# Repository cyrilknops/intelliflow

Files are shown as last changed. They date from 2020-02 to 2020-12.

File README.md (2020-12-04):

# Intelliflow
Intelliflow is a IoT project made by Cyril Knops, Joost Van der Linden, Ferre Claes, Glen Van Puyenbroeck and Emile Knaepen. The goal is to design a pcb and firmware for the [ESP32](https://www.espressif.com/en/products/socs/esp32/overview) that can interface with generic sensors and communicate with a dashboard. The data that is send to the dashboard are the different sensor values.
## System Overview
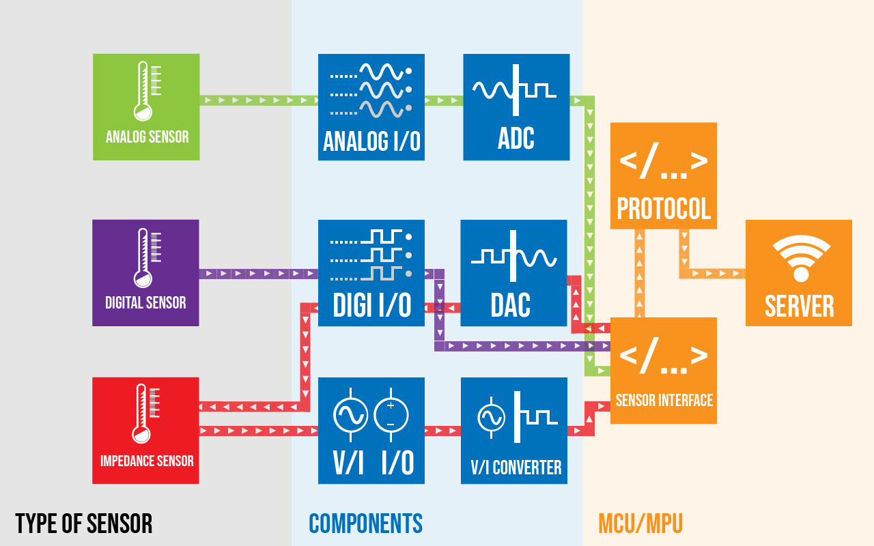
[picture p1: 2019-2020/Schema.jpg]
Flowdiagram

## How to use
There are a few differen directories with each its own project:
* [dashboard written in angularjs](https://github.com/cyrilknops/intelliflow/tree/master/test-dashboard)
* [firmware for sending temperatures to the server](https://github.com/cyrilknops/intelliflow/tree/master/MQTT%2BProtobuf/Intelliflow)
* [firmware to change the settings of the esp](https://github.com/cyrilknops/intelliflow/tree/master/Console)
* [a test firmware that tests the speed of the different protocols (MQTT, Wi-Fi and protobuf)](https://github.com/cyrilknops/intelliflow/tree/master/IntelliflowAN)

most of them have a readme file in them which explains how to use and configure the different tings
## Build with
* [C](https://en.wikipedia.org/wiki/C_(programming_language)) - The programming language used
* [MQTT](http://mqtt.org/) - The communication protocol used
* [Sparkfun ESP32 Thing](https://www.sparkfun.com/products/13907) - The development boeard used
## Authors
* Cyril Knops - ESP32 Network, ESP32 CLI
* Joost Van der Linden - ESP32 Sensor connection
* Glen Van Puyenbroeck - PCB Design
* Ferre Claes - Sensor components
* Emile Knaepen - ESP32 Sensor Libraries
* Bart Stukken - Scrum master
* Koen Gilissen - Product owner
## Links
[Component list](https://hogeschoolpxl-my.sharepoint.com/:x:/r/personal/11800025_student_pxl_be/_layouts/15/Doc.aspx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)
<br/>
[Order list](https://hogeschoolpxl-my.sharepoint.com/:x:/g/personal/11700872_student_pxl_be/ETT0oJHQHUZLjarLOVaMEmgBshADOvq9l2GqsdMUGDBhIA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)
<br/>
[Wiki](https://github.com/cyrilknops/intelliflow/wiki)

## License
This project is licensed under the MIT License

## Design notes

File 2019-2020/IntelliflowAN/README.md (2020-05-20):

# Speed test for the ESP32
This project can test for 3 things:
* Wi-Fi connection
* Protobuf conversion
* MQTT connection

## Configuration
In the config.h file change the following things
```c
const char* ssid = "Your_ssid";
const char* password = "Your_pwd";
const char* mqtt_server = "intelliflow.pxl-ea-ict.be"; //change this to your mqtt broker adress
```
## How to run
Open the project in arduino ide and upload to the ESP32

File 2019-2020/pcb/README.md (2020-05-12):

# PCB Prototype 

Here you can find the schematics of the PCB prototype. 

Included in this workspace: 

- 3D map : In this map are the used 3D models of the prototype
- PCB_Project : Here in this map are the schematics , project and PCB files of the project

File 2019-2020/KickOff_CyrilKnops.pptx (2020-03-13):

## Intelliflow

Cyril Knops

## Probleemstelling

- In de voedings industrie is het vaak onduidelijk wat er in het proces gebreurd.
  - Er worden weinig tot geen sensoren gebruikt
  - Hierdoor worden tonnen/liters gronstoffen soms weggegooid
  - Waardevolle tijd verspild omdat complete processen moeten worden onderbroken

## Materiaal & methoden

- Een simple MPU met externe ADC+DAC
  - Goedkoper wanneer er geen ADC nodig is
  - Hogere resolutie bij externe ADC+DAC
  - Meer keuze qua MPU vb: esp(ingebouwde WIFI)
  - Stroom naar spanning converter
- Welke methoden ga ik gebruiken
  - Low overhead netwerk protocol
  - Meerdere sensoren per MPU mogelijk
  - High throughput protocol tussen ADC/DAC en MPU

## Milestones

- 17/03/20 24u
  - Definitieve keuze MPU ADC/DAC Network Protocol
- 31/03/20 24u
  - 1st demo-implementatie 1 sensor op breadboard
  - (PCB frezen)
- 28/04/20 24u
  - Implementatie sofware meerdere sensoren compleet
- 19/05/20 24u
  - Definitief project
  - (PCB af)
- 27/05/20 8u30
  - Extra controle

## Taakverdeling

- Cyril
  - Hoofdverantwoordelijke voor algemene integratie
  - Verantwoordelijke voor Communicatie met server
- Rein
  - Verantwoordelijke voor sensor interface
- Glen
  - Verantwoordelijke voor PCB design
- Ferre
  - Verantwoordelijke voor component keuze/inlezen ADC/DAC

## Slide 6

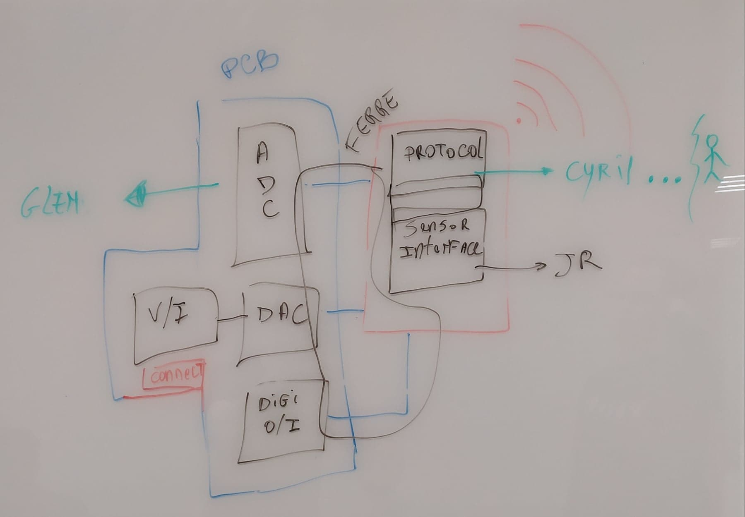
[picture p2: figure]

## Onderzoeksvraag

- Hoe kunnen we op een economische en ecologische manier verschillende stoffen meten en omzetten naar bruikbare data om het voedsel process te stroomlijnen?

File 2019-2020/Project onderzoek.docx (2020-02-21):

Project onderzoek.

Notities Microcontroller ESP32 mogelijkheden .

Datum : 21/02/2020

Input spanning : 2.3 – 3.6 volt.

Gebruikt arduino IDE voor de software.

Onderdelen :

- Processoren:
  - CPU: Xtensa dual-core (of single-core) 32-bit LX6 microprocessor, klokfrequentie van 160 of 240 MHz. (Achterhoofd houden)
  - Ultra-low power (ULP) co-processor Leuk extra
- Geheugen: 520 KiB SRAM (https://nl.wikipedia.org/wiki/Static_random-access_memory)
- Draadloze verbindingsmogelijkheden:
  - Wi-Fi: 802.11 (https://nl.wikipedia.org/wiki/IEEE_802.11) b/g/n
  - Bluetooth: v4.2 BR / EDR en BLE
- Perifere interfaces:
  - 12-bit SAR ADC (https://nl.wikipedia.org/wiki/Analoog-digitaalomzetter) tot 18 kanalen (lage ADC , ligt wel iets hoger dan de ESP8226 (10 bit))

ADC voor intelloflow project zou 21 bit moeten zijn

Externe ADC mogelijk ? (zie pagina 2)

  - 2 × 8-bit DAC's (https://nl.wikipedia.org/wiki/Digitaal-analoogomzetter) (Heel laag )
  - 10 × aanraaksensoren (GPIO's met capacitieve detectie)
  - 4 × SPI (https://nl.wikipedia.org/wiki/Serial_Peripheral_Interface)
  - 2 × I²S- interfaces
  - 2 × I²C (https://nl.wikipedia.org/wiki/I%C2%B2C-bus) interfacebus
  - 3 × UART
  - SD (https://nl.wikipedia.org/wiki/SD-kaart) / SDIO (https://nl.wikipedia.org/wiki/SD-kaart) / CE-ATA / MMC (https://nl.wikipedia.org/wiki/MMC-kaart) / eMMC (https://nl.wikipedia.org/wiki/MMC-kaart) hostcontroller
  - SDIO / SPI-slave-controller
  - Ethernet (https://nl.wikipedia.org/wiki/Ethernet) MAC-interface met speciale ondersteuning voor DMA en IEEE 1588 Precision Time Protocol
  - CAN bus (https://nl.wikipedia.org/wiki/Controller_Area_Network) 2.0
  - Infrarood afstandsbediening (TX / RX, maximaal 8 kanalen)
  - Motor PWM (https://nl.wikipedia.org/wiki/Pulsbreedtemodulatie)
  - LED PWM (https://nl.wikipedia.org/wiki/Pulsbreedtemodulatie) (tot 16 kanalen)
  - Hall-effect sensor (https://nl.wikipedia.org/wiki/Hall-sensor)
- Beveiligingstechnieken:
  - Standaard IEEE 802.11-beveiligingsfuncties die worden ondersteund, inclusief WFA, WPA / WPA2 en WAPI
  - Beveiligd opstartproces
  - Flash-codering
  - 1024-bit OTP, tot 768-bit voor klanten
  - Cryptografische hardwareversnelling: AES (https://nl.wikipedia.org/wiki/Advanced_Encryption_Standard), SHA-2, RSA (https://nl.wikipedia.org/wiki/RSA_(cryptografie)), elliptische curve-cryptografie (ECC), random number generator (RNG)
- Stroombeheer:
  - Interne drop-out regelaar (https://nl.wikipedia.org/wiki/Spanningsregelaar)
  - 5μA stroom in deep-sleep mode Leuk extra
  - Wake up van sleep mode door GPIO interrupt, timer, ADC of interrupt door capacitieve aanraaksensor. (Totaal interruptslijnen = 32 )

Bron Algemene informatie = https://nl.wikipedia.org/wiki/ESP32

Bron interrupts = https://lastminuteengineers.com/handling-esp32-gpio-interrupts-tutorial/

Externe ADC’s zijn mogelijk tot 24 bit. Component ads1256 gaat tot 24 bit

.http://www.ti.com/lit/ds/symlink/ads1256.pdf

Bibliotheek hoeft niet zelf geschreven te worden. Is vrij beschikbaar.

https://www.youtube.com/watch?v=LjLwvXKz2x8

Conclusie :

- Makkelijk programmeerbaar.
- Code ivm met wifi is duidelijk en makkelijk toe te passen.
- Open source code is makkelijk te vinden.
- Heeft veel eigen bibliotheken .
- Mogelijkheid voor de ADC drastisch te verhogen met de ads1256 component
- Bibliotheek voor de ADS1256 moet niet zelf geschreven worden , vrij beschikbaar.
- Samples per seconde kan makkelijk aangepast worden

Verdere onderzoek voor een andere dag:

- Verschillende bordjes beschikbaar van de ADS1256. Welke is betrouwbaar ?
- Technische specificaties van de ADS1256 is bekijken.
- Code is bestuderen.
- Prijzen opzoeken.
- Ook mogelijkheid met ESP8266 , PSOC6 wifi en andere ?

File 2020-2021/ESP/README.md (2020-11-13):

# instructions

Add a config.h to the root of your arduino project containing the following:
``` c++
const char* ssid = "SSID"; //change this to the SSID of your Wi-Fi network
const char* password = "*********"; //change this to the password of your Wi-Fi network
const char* mqtt_server = "home.iwg-it.com"; // change this to your mqtt broker url or ip
const int mqtt_port = 24075; //change this to your mqtt broker port
```

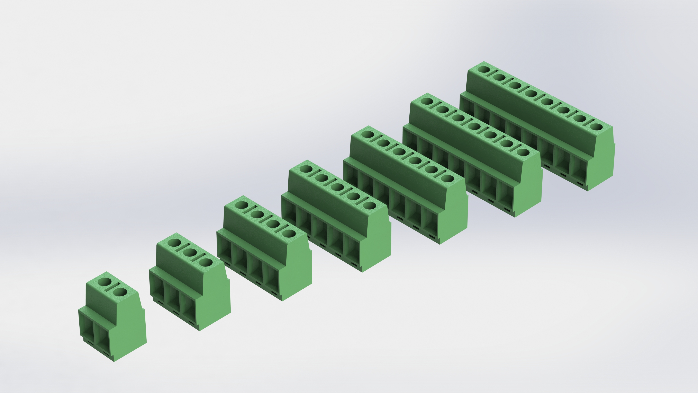
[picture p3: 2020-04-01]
2020-2021/PCB/PCBontwerpen/3D/em2929-series-euromag-terminal-blocks-1.snapshot.2/Rendering.JPG

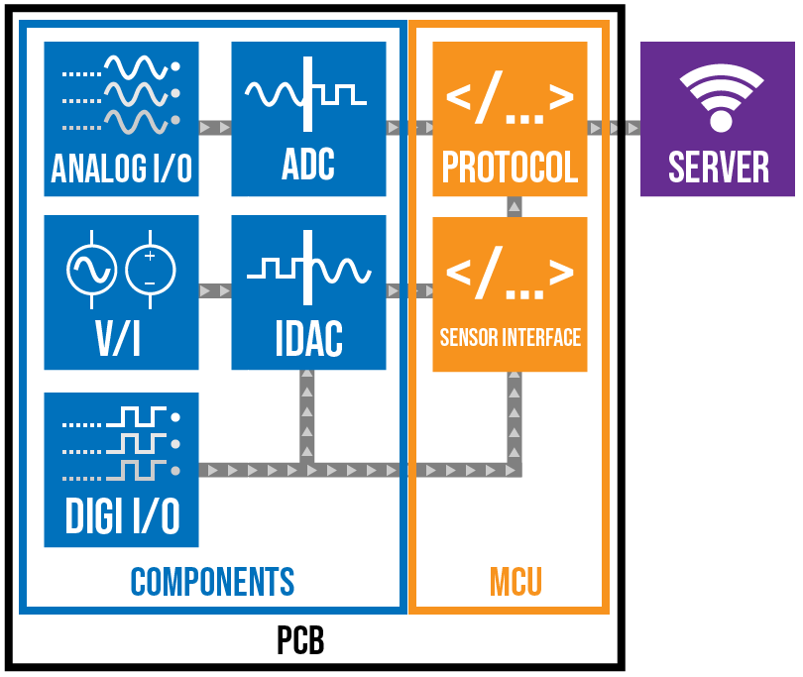
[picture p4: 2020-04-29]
2019-2020/2020-04-26 14_32_01-Untitled-1.ai_ @ 100% (RGB_Preview).png

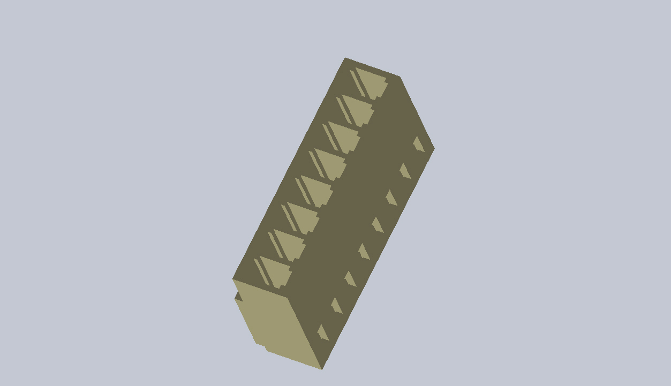
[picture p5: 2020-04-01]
2020-2021/PCB/PCBontwerpen/3D/CI32 8 PIN FEMALE_3.JPG

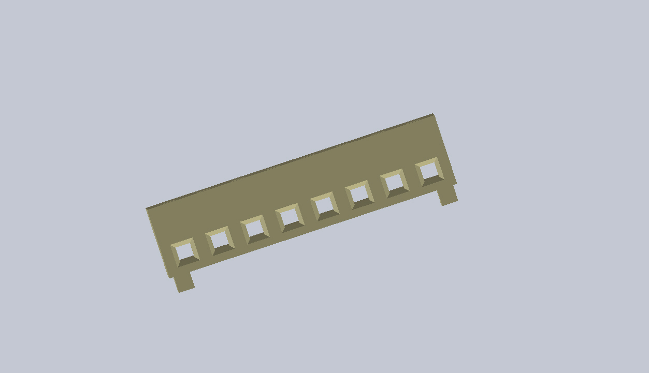
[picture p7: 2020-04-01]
2020-2021/PCB/PCBontwerpen/3D/CI32 8 PIN FEMALE_2.JPG

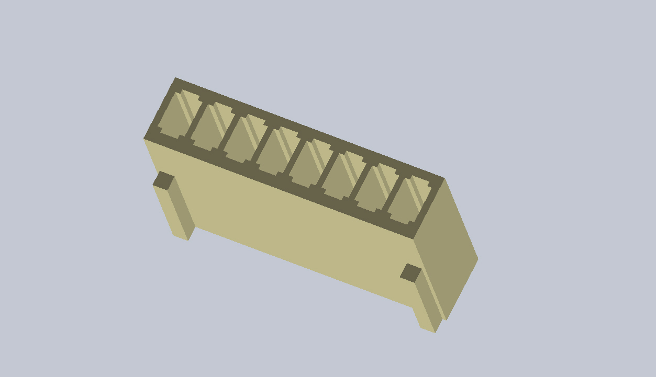
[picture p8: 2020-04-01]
2020-2021/PCB/PCBontwerpen/3D/CI32 8 PIN FEMALE_.JPG

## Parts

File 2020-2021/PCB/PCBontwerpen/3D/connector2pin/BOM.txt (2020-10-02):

3DX_CUI_DEVICES_Supplier: CUI Devices
3DX_CUI_DEVICES_Description: 2~24 Poles, Screwless, 45°, 5.00 Pitch, 26~14 (AWG), Terminal Block Connector
3DX_CUI_DEVICES_Model Number: TBL007A-500-02GY

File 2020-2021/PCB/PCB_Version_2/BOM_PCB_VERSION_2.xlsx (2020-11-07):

Beschrijving | Regular ID | Link | ID Mouser | Price/Piece | Amount/PCB | Total/PCB | Form
ESP32 | NodeMCU-32 | https://www.az-delivery.de/en/products/esp32-developmentboard?_pos=13&_sid=d3f4f9e85&_ss=r | NodeMCU-32 | EUR 7.99 | 1 | EUR 7.99 | Trough Hole
Terminal Block Size 2 | TB004-508-02BE | https://www.mouser.be/ProductDetail/CUI-Devices/TB004-508-02BE | 490-TB004-508-02BE | EUR 0.53 | 2 | EUR 1.06 | Trough Hole
Terminal Block Size 4 | TB004-508-04BE | https://www.mouser.be/ProductDetail/CUI-Devices/TB004-508-04BE | 490-TB004-508-04BE | EUR 0.81 | 6 | EUR 4.86 | Trough Hole
Terminal Block Size 8 | TB004-508-08BE | https://www.mouser.be/ProductDetail/CUI-Devices/TB004-508-08BE | 490-TB004-508-08BE | EUR 1.30 | 1 | EUR 1.30 | Trough Hole
ADC | ADS1247IPWR | https://www.mouser.be/ProductDetail/Texas-Instruments/ADS1247IPWR?qs=XGzIaZb%2FFYLO0W6RE5uyhw%3D%3D | 595-ADS1247IPWR | EUR 8.07 | 1 | EUR 8.07 | IC
DAC | DAC70504RTET | https://www.mouser.be/ProductDetail/Texas-Instruments/DAC70504RTET | 595-DAC70504RTET | EUR 11.69 | 1 | EUR 11.69 | IC
OP-AMP | LTC6241CS8#PBF | https://www.mouser.be/ProductDetail/?qs=hVkxg5c3xu%252BfRCzMDOZ5vQ%3D%3D | 584-LTC6241CS8#PBF | EUR 2.64 | 1 | EUR 2.64 | IC
DIP-Switch | CES-0402MC | https://www.mouser.be/ProductDetail/Nidec-Copal/CES-0402MC?qs=XeJtXLiO41Q05topIs8SoQ%3D%3D | 229-CES-0402MC | EUR 1.37 | 1 | EUR 1.37 | Trough Hole
Header Set | PRT-14311 | https://www.mouser.be/ProductDetail/SparkFun/PRT-14311?qs=YCa%2FAAYMW01YBV4voM9QGw%3D%3D | 474-PRT-14311 | EUR 1.37 | 1 | EUR 1.37 | Trough Hole
DC-Power socket | PJ-002BH | https://www.mouser.be/ProductDetail/CUI-Devices/PJ-002BH?qs=WyjlAZoYn51nOX1h%2FqpLlg%3D%3D | 490-PJ-002BH | EUR 0.63 | 1 | EUR 0.63 | Trough Hole
Capaciteit (1µF) | C0805X105K8RAC7210 | https://www.mouser.be/ProductDetail/KEMET/C0805X105K8RAC7210 | 80-C0805X105K8RACLR | EUR 0.75 | 1 | EUR 0.75 | SMD 0805
Capaciteit (0,1µF) | C0805X104M5RACTU | https://www.mouser.be/ProductDetail/KEMET/C0805X104M5RACTU | 80-C0805X104M5RACTU | EUR 0.44 | 2 | EUR 0.88 | SMD 0805
Capaciteit (1nF) | C0805X102F5GACTU | https://www.mouser.be/ProductDetail/KEMET/C0805X102F5GACTU?qs=AQlKX63v8RtxfgGJTbOcaw%3D%3D | 80-C0805X102F5G | EUR 1.59 | 1 | EUR 1.59 | SMD 0805
Weerstand (47Ω) | ERA-6VEB47R0V | https://www.mouser.be/ProductDetail/Panasonic/ERA-6VEB47R0V | 667-ERA-6VEB47R0V | EUR 0.59 | 5 | EUR 2.95 | SMD 0805
Weerstand (500Ω) | RN732ATTD5000B25 | https://www.mouser.be/ProductDetail/KOA-Speer/RN732ATTD5000B25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 | 660-RN732ATTD5000B25 | EUR 0.71 | 2 | EUR 1.43 | SMD 0805
 |  |  |  |  | Total Price: | EUR 48.58

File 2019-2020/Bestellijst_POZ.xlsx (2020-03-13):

Mouser |  |  |  | Reichelt |  |  |  | Conrad |  |  |  | Extra
Link | ID | Price | Amount | Link | ID | Price | Amount | Link | ID | Price | Amount | Link | ID | Price | Amount
 |  | EUR 0.00 | 0 |  |  | EUR 0.00 | 0 |  |  | EUR 0.00 | 0 |  |  | EUR 0.00 | 0
TOTAL |  | EUR 0.00 | 0 |  |  | EUR 0.00 | 0 |  |  | EUR 0.00 | 0 |  |  | EUR 0.00 | 0

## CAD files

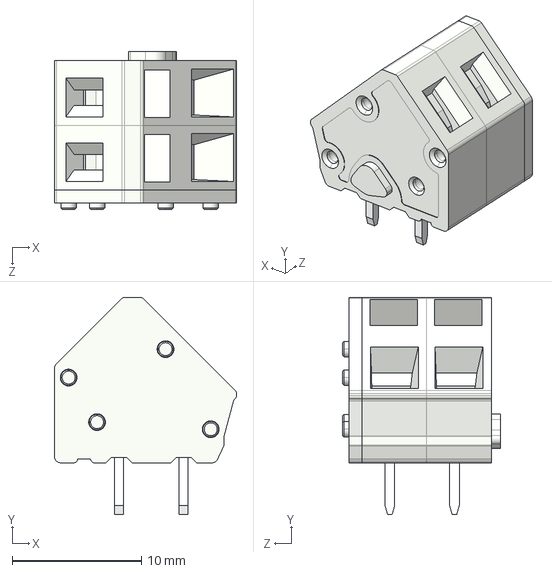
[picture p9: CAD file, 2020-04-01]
2019-2020/pcb/PCBontwerpen/3D/connector2pin/CUI_DEVICES_TBL007A-500-02GY.step
14.1 x 16.8 x 12.2 mm

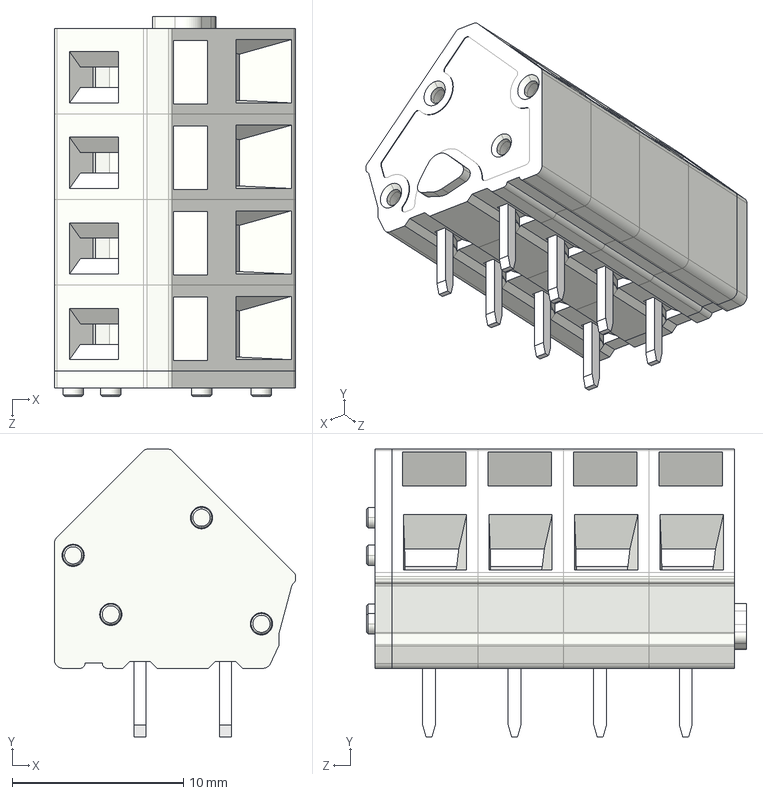
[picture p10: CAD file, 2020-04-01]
2019-2020/pcb/PCBontwerpen/3D/connector4pin/CUI_DEVICES_TBL007A-500-04GY.step
14.1 x 16.8 x 22.2 mm

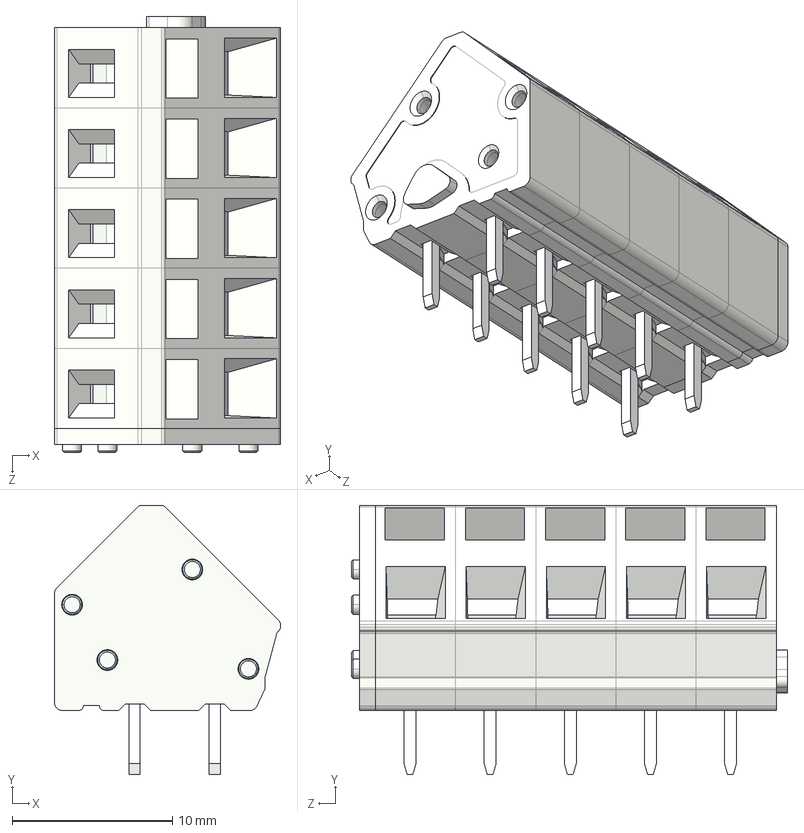
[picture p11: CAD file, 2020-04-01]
2019-2020/pcb/PCBontwerpen/3D/connector5pin/CUI_DEVICES_TBL007A-500-05GY.step
14.1 x 16.8 x 27.2 mm

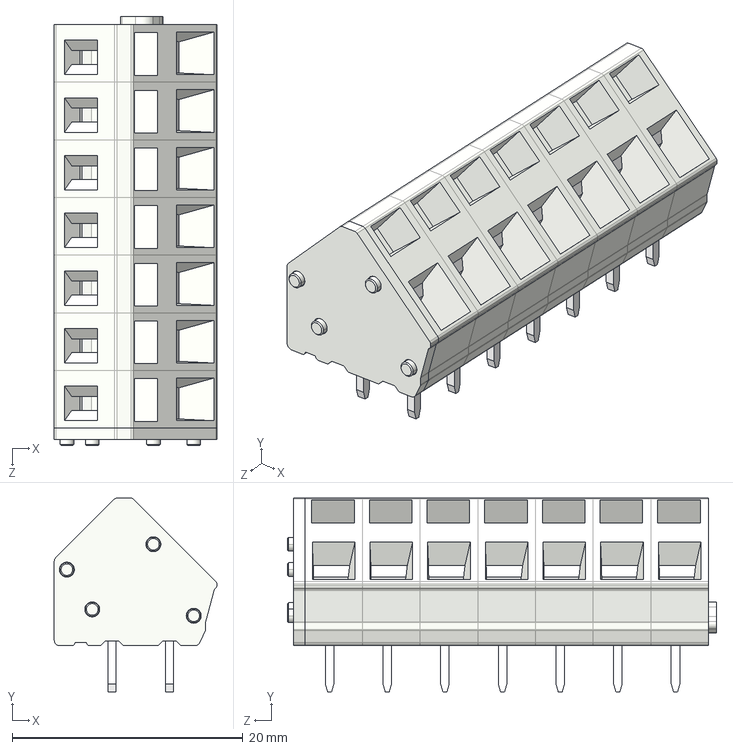
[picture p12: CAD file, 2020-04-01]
2019-2020/pcb/PCBontwerpen/3D/connector7pin/CUI_DEVICES_TBL007A-500-07GY.step
14.1 x 16.8 x 37.2 mm

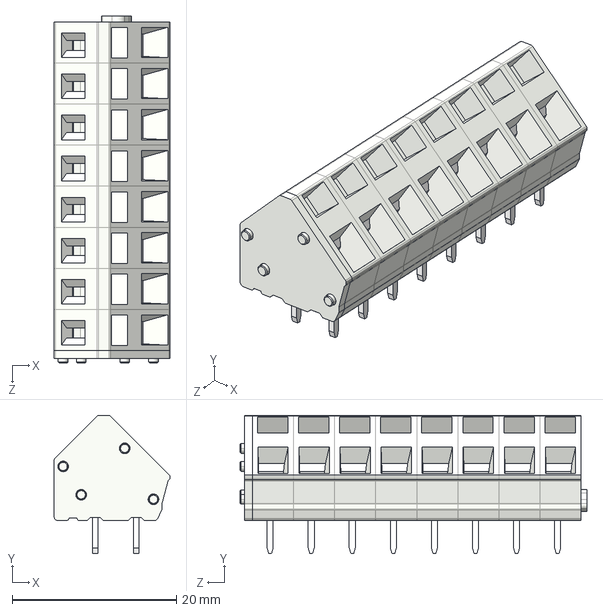
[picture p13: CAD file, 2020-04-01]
2019-2020/pcb/PCBontwerpen/3D/connector8/CUI_DEVICES_TBL007A-500-08GY.step
14.1 x 16.8 x 42.2 mm

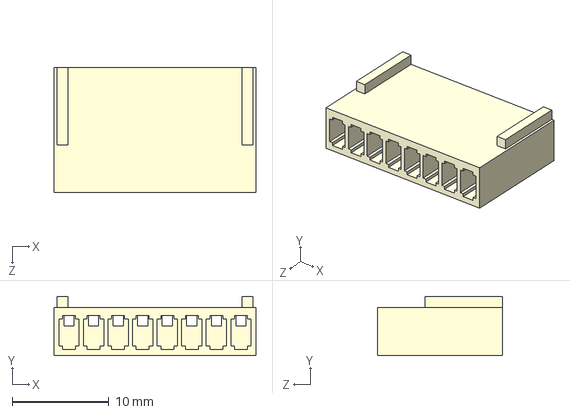
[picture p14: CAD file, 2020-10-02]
2020-2021/PCB/PCBontwerpen/3D/CI32 8 PIN FEMALE_.STEP
20.9 x 6.15 x 13.0 mm

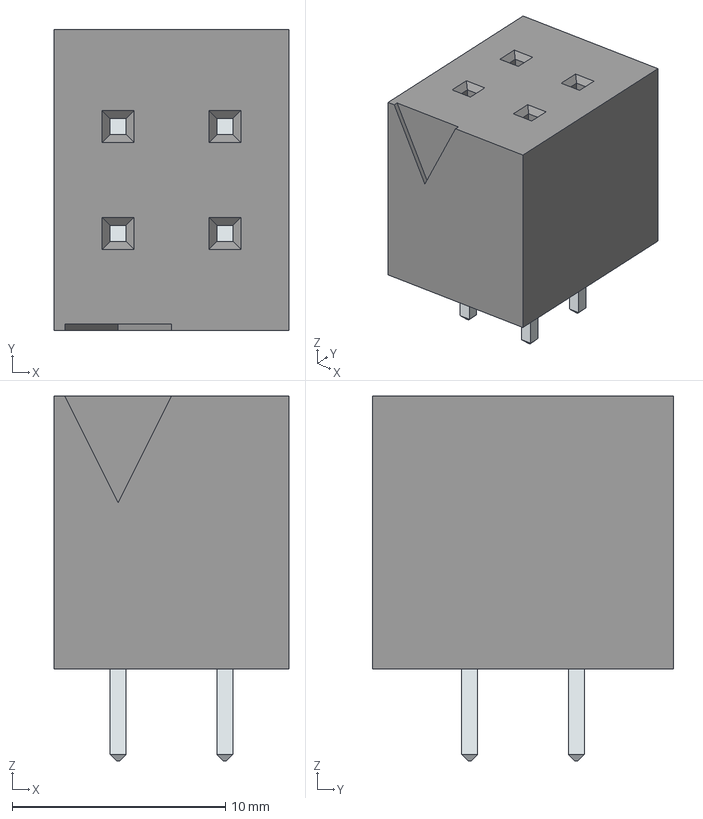
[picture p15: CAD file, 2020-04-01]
2020-2021/PCB/PCBontwerpen/3D/TBL007A-500-02GY/3D/TBL007A-500-02GY.stp
11.0 x 14.1 x 17.1 mm
LeadsArray

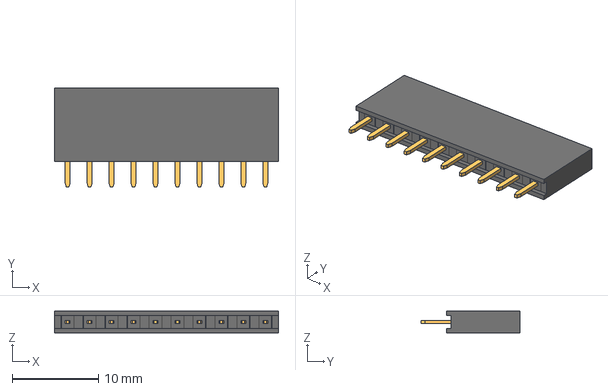
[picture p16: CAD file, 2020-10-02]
2020-2021/PCB/PCBontwerpen/3D/zl262-10s_p2-54_l25-9_w2-5_h8-5.stp
25.9 x 11.5 x 2.54 mm

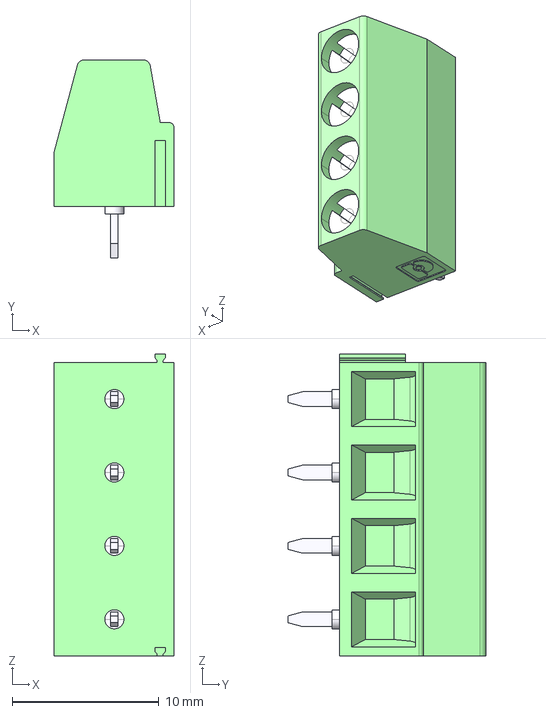
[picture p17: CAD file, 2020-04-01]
2019-2020/pcb/PCBontwerpen/3D/1729034/3D/1729034.stp
8.15 x 13.5 x 20.6 mm

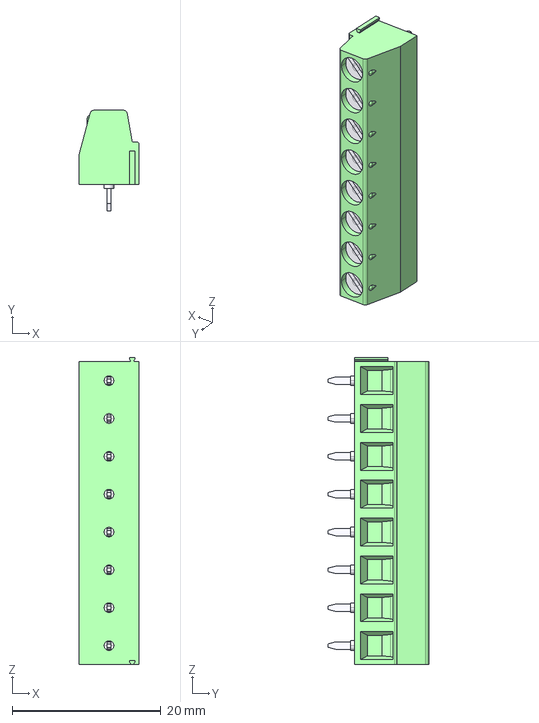
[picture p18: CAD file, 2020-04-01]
2019-2020/pcb/PCBontwerpen/3D/1729186/3D/1729186.stp
8.10 x 13.5 x 41.2 mm

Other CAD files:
2020-2021/PCB/PCBontwerpen/3D/connector2pin/CUI_DEVICES_TBL007A-500-02GY.step
2020-2021/PCB/PCBontwerpen/3D/connector4pin/CUI_DEVICES_TBL007A-500-04GY.step
2020-2021/PCB/PCBontwerpen/3D/connector5pin/CUI_DEVICES_TBL007A-500-05GY.step
2020-2021/PCB/PCBontwerpen/3D/connector7pin/CUI_DEVICES_TBL007A-500-07GY.step
2020-2021/PCB/PCBontwerpen/3D/connector8/CUI_DEVICES_TBL007A-500-08GY.step
2020-2021/PCB/PCBontwerpen/3D/1729034/3D/1729034.stp
2020-2021/PCB/PCBontwerpen/3D/1729186/3D/1729186.stp
2020-2021/PCB/PCBontwerpen/3D/CI32 8 PIN FEMALE_.IGS
2020-2021/PCB/PCBontwerpen/3D/CI32 8 PIN FEMALE_.SLDPRT
2020-2021/PCB/PCBontwerpen/3D/TBL007A-500-02GY.stl
2020-2021/PCB/PCBontwerpen/3D/TBL007A-500-02GY/3D/TBL007A-500-02GY.stl
2020-2021/PCB/PCBontwerpen/3D/em2929-series-euromag-terminal-blocks-1.snapshot.2/EM292902-UL.SLDPRT
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

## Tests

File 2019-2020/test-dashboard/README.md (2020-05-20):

# Test dashboard
This dashboard is created to test the MQTT and REST API connection to the server.

# Configuration
Change the URL in the index.html file to the URL where your server is running

# How to run
Just download the files and open the index.html

# Buid with
* [AngularJS framwork](https://angularjs.org/) - the framework that makes it all work

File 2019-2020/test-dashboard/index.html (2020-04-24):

# Intelliflow

Show list

Amount of measurements: {{vm.amount}} | | Current Temp: {{vm.temp}} | | Time of measurement: {{vm.timestamp | date : "dd/mm/yy 'at' HH:mm:ss"}}
Timestamp | temperature
{{temp.time | date : "dd/mm/yy 'at' HH:mm:ss"}} | {{temp.temperature}}

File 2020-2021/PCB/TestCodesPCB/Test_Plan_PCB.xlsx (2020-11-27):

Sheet: PCB v1
Testplan PCB
Short | Test | No heat | Heat
 | No Heat ADC | x
 | No Heat DAC | x
 | No Heat ESP32 | x
 | No Heat capacitors | x
Comment | Everything seems fine , ADC is a little warm but temp stays constant
Volt and ground | Test | Present | Not present
 | 3,3 V where 3,3V should be | x
 | 5 V where 5V should be | x
Comment | 3,29V = 3,3V
GPIO's ESP32 | Test Input | Succes | Failed
 | GPIO39 / ADC 3 |  |  | forgot to document , recheck
 | GPIO34 / ADC 6 | x
 | GPIO35 / ADC 7 | x
 | GPIO32 / ADC 4 | x
Comment | Test is done with a analog light sensor
GPIO's ESP32 | Test output | Succes | Failed
 | GPIO36 / ADC0 ( SS DAC) |  | x | input only
 | GPIO39 / ADC 3 |  | x | input only
 | GPIO34 / ADC 6 |  | x | input only
 | GPIO35 / ADC 7 |  | x | input only
 | GPIO32 / ADC 4 | x
 | GPIO5 (SS OUTBOARD) | x
 | GPIO15 (SS ADC) | x
 | GPIO2 (START ADC) | x
 | GPIO8 (DRYD ADC) |  | x | only 1,17 volt doenst turn of
 | GPIO7 (RESET ADC) |  | x
Comment | date = 24/10/2020 . Maybey only input pins (39,34,35,32) ? Recheck datasheet
 | date = 25/10/2020 . Pin 33 went high in a previous test but not pin 32 ? Recheck pin .
 | data = 25/10/2020. Pin 36 is wrongly placed , should be an output , test should fail
 | date = 30/10/2020, Test completed , pin GPIO7 and GPIO8 failed (check datasheet)
 | date = 30/10/2020, GPIO8 needs to go low after converting (see 9,4,4) | GPIO8 can be used as MOSI
 | date = 30/10/2020, GPIO7 doesnt go high (see 9.4.2) | GPIO7 can be used as MISO
UART | Test | Succes | Failed
 | An UART module works |  |  | optional
 | Sending and recieving string | x
Comment | test done with psoc 4
I2C | Test | Succes | Failed
 | Reading data I2C sensor | x
 | Sending and recieving string
Comment | Test is done with a tempature sensor (SCL and SDA are switched)
SPI | Test | Succes | Failed
 | Reading data SPI sensor |  |  | optional
 | Sending and recieving charaters | x
Comment | test done with psoc 4
ADC 1247 | Test | Succes | Failed
 | Connection possible with SPI |  |  | cancelled due to hardware problems
 | Reading an analog sensor |  |  | cancelled due to hardware problems
Comment
DAC 70504 | Test | Succes | Failed
 | Connection possible with SPI |  |  | cancelled due to hardware problems
 | Output current is |  |  | cancelled due to hardware problems
Comment

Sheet: Speedcheck PCB v1
UART | Recieving data on | Recieved | Not received
 | 1200 bps | x
 | 2400 bps | x
 | 4800 bps | x
 | 9600 bps | x
 | 19200 bps | x
 | 38400 bps | x
 | 57600 bps | x
 | 115200 bps | x
Comment | 08/11/2020 = Test completed with psoc4 no errors
 | note : esp32 can't be programmend with TX pluged in
 | https://learn.sparkfun.com/tutorials/serial-communication/all
I2C part 1 | Measerment SCL | Approved | Not approved
 | Standard mode : 100 Kbit/s |  |  | Not the possibility for measerment I2C bus on avaible oscilloscope
 | Fast mode : 400 Kbit/s |  |  | Not the possibility for measerment I2C bus on avaible oscilloscope
 | Recieved data on | Recieved | Not recieved
 | Standard mode : 100 Kbit/s | x
 | Fast mode : 400 Kbit/s | x
Comment | 10/11/2020 = MCP9808 temp sensor got 100 khz and 400 khz posibility , test completed
 | https://dcubestore.com/product/mcp9808-high-accuracy-digital-temperature-sensor-%C2%B10-25-from-40c-to-125c-i2c-mini-module/
SPI OUTBOARD | SPI half duplex on (sending data to psoc 4) | Approved | Failed
 | 24 MHZ |  | x | Somtimes corruption in data
 | 12 MHZ | x
 | 6 MHZ | x
 | 3 MHZ | x
 | 1,5 MHZ | x
Comment | 22/11/2020 = test completed. Note: bitwise << 1 is needed while sending to psoc , loss LSB bit
 | 27/11/2020 = Lost LSB fit is from the PSOC SPI block https://community.cypress.com/thread/26206?start=0&tstart=0
 | SPI full duplex on (sending and recieving data psoc 4) | Recieved data | Failed
 | 24 MHZ |  | x | More corruption in data
 | 12 MHZ | x
 | 6 MHZ |  | x | ESP MISO recieves garbage , psoc MOSI recieves data as normal
 | 3 MHZ |  | x | ESP MISO recieves garbage , psoc MOSI recieves data as normal
 | 1,5 MHZ |  | x | ESP MISO recieves garbage , psoc MOSI recieves data as normal
Comment | 22/11/2020 = test completed, only 12MHZ on MISO ?
 | 27/11/2020 = changing external clock doenst have effect on SPI block psoc https://community.cypress.com/thread/26206?start=0&tstart=0
SPI ADC 1247 | Measerment SCLK to ADC 1247 | Approved | Not approved
 | SPI_CLOCK_DIV2 = 80 MHZ |  |  | cancelled due to hardware problems
 | SPI_ClOCK_DIV8 = 20 MHZ |  |  | cancelled due to hardware problems
 | SPI_ClOCK_DIV32 = 5 MHZ |  |  | cancelled due to hardware problems
 | SPI_ClOCK_DIV128 = 1,25 MHZ |  |  | cancelled due to hardware problems
 | Recieved data on | Recieved | Not recieved
 | SPI_CLOCK_DIV2 = 80 MHZ |  |  | cancelled due to hardware problems
 | SPI_ClOCK_DIV8 = 20 MHZ |  |  | cancelled due to hardware problems
 | SPI_ClOCK_DIV32 = 5 MHZ |  |  | cancelled due to hardware problems
 | SPI_ClOCK_DIV128 = 1,25 MHZ |  |  | min is 480 ns or around 2 Mhz , should fail
Comment
SPI DAC 70504 | Measerment SCLK to DAC 70504 | Approved | Not approved
 | SPI_CLOCK_DIV2 = 80 MHZ |  |  | cancelled due to hardware problems
 | SPI_ClOCK_DIV8 = 20 MHZ |  |  | cancelled due to hardware problems
 | SPI_ClOCK_DIV32 = 5 MHZ |  |  | cancelled due to hardware problems
 | SPI_ClOCK_DIV128 = 1,25 MHZ |  |  | cancelled due to hardware problems
 | Recieved data on | Recieved | Not recieved
 | SPI_CLOCK_DIV2 = 80 MHZ |  |  | cancelled due to hardware problems
 | SPI_ClOCK_DIV8 = 20 MHZ |  |  | cancelled due to hardware problems
 | SPI_ClOCK_DIV32 = 5 MHZ |  |  | cancelled due to hardware problems
 | SPI_ClOCK_DIV128 = 1,25 MHZ |  |  | cancelled due to hardware problems
Comment

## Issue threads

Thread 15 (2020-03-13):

voorbereiding pcb ontwerp designen in Altuim.

Reinvanderlinden, 2020-03-13:
Connectoren en componenten toevoegen in altium

Glen-tech, 2020-03-18:
- ADC footprint en schematic is in orde gebracht
- Alle connectoren schematic en footprints zijn in orde ( 4 pins , 5 pins en 8 pins zelf moeten maken).

**DAC en ESP moet nog toegevoegt worden**

Glen-tech, 2020-03-20:
ESP schematic toegevoegt

ESP footprint , DAC + current to voltage moet nog worden toegevoegt

Glen-tech, 2020-03-31:
Alle footprints en 3d moddelen werden toegevoegt . Bewijs hiervan volgt nog.

Glen-tech, 2020-05-06:
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

Closed 2020-05-06.

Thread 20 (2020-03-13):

Connector Sensor-ADC/DAC

Reinvanderlinden, 2020-03-13:

Glen-tech, 2020-03-14:
- Connectoren zonder schroef werd uitgekozen
- Alle 3 dezelfde merk plus dezelfde kleur
- 3 leveranciers gevonden , laatste lijkt me niet 100 betrouwbaar

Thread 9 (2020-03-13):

Het opstellen van de elektrische schema voor breadboard prototype en test PCB's.

Reinvanderlinden, 2020-03-13:

Glen-tech, 2020-03-20:
- ADC circuit is toegevoegt , alleen condensatoren en SPI verbinding zou nog gedaan moeten worden.
- DAC circuit moet nog volledig gedaan worden.

Glen-tech, 2020-05-06:
Volledige test schema is afgerond
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

Closed 2020-05-06.

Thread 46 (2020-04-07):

problems pcb

FerreClaes, 2020-04-07:

FerreClaes, 2020-04-07:
- [ ] reset adc niet aangesloten

- [ ] drdy adc niet aangesloten

Glen-tech, 2020-04-08:
-Alle T splitsingen is nakijken tegen volgende keer en de 45 graden hoeken.
-Condensatoren 8 , 9 , 10 en 11 verder uit elkaar zetten voor 45 graden hoeken te maken

Glen-tech, 2020-04-10:
- Connectie diktes werd aangepast
- Connectoren onder mogen wat verder uit elkaar

Glen-tech, 2020-04-10:
- Traces zijn nu op de juiste dikte
- Condensatoren moet nog gebeuren

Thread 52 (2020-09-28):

DAC schema en footprint

Glen-tech, 2020-09-28:
- Aanmaak Dac + toevoeging schema is gebeurd.
- Footprint moet nog aangemaakt worden.

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

Glen-tech, 2020-09-28:
2d en 3d footprint zitten erbij

dit klopt met de designators

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

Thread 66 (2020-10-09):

PCB Versie 1 uittesten

FerreClaes, 2020-10-09:

Glen-tech, 2020-10-13:
Test 1 (voeding) korte samenvatting
  - Geen rookvorming
  - ESP32 heeft normale temperatuur
  - Alles is 3.3 V waar het moet zijn en 5V waar het moet zijn
  - Geen warmte bij de DAC
  - Beetje warmte bij de ADC , dit blijft constant.

Glen-tech, 2020-10-15:
Test2 I2C en digitale ingangen

- I2C vertoont geen problemen  met uitlezen van sensoren (SDA en SCL tekst PCB staat omgedraait)
- Dit geld ook bij de connector digitale ingangen .

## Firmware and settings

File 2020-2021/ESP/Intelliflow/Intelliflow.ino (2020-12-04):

#include <EEPROM.h>
#include <WiFi.h>
#include <PubSubClient.h>
//protobuf includes
#include <pb.h>
#include <pb_common.h>
#include <pb_encode.h>
#include "intelliflow.pb.h"
//sensor includes
#include <Wire.h>
#include "Adafruit_TCS34725.h"
#include "Adafruit_SGP30.h"
//CLI  
#define LINE_BUF_SIZE 128   //Maximum input string length
#define ARG_BUF_SIZE 64     //Maximum argument string length
#define MAX_NUM_ARGS 8      //Maximum number of arguments
bool error_flag = false;
char line[LINE_BUF_SIZE];
char args[MAX_NUM_ARGS][ARG_BUF_SIZE];
int cmd_help();
int cmd_wifi();
int cmd_mqtt();
int (*commands_func[])(){
    &cmd_help,
    &cmd_wifi,
    &cmd_mqtt,
    &cmd_cli,
    
};
const char *commands_str[] = {
    "help",
    "wifi",
    "mqtt",
    "cli"
};
int num_commands = sizeof(commands_str) / sizeof(char *);
bool cliMode;
//Sensors
Adafruit_TCS34725 tcs = Adafruit_TCS34725(TCS34725_INTEGRATIONTIME_700MS, TCS34725_GAIN_1X);
Adafruit_SGP30 sgp;
//Settings
String ssid;
String password;
String url;
String port;
//wifi connection
WiFiClient espClient;
//mqtt
int trys = 0;
int wifiTrys = 0;
PubSubClient client(espClient);
long lastMsg = 0;
char msg[50];
uint32_t  messages = 0;
uint32_t succes = 0;
//protobuf
int values = 0;

void setup() {
  //status led
  pinMode(BUILTIN_LED, OUTPUT);
  //serialg
  Serial.begin(115200);
  EEPROM.begin(400);
  ssid = EEPROM.readString(0);
  password = EEPROM.readString(100);
  url = EEPROM.readString(200);
  port = EEPROM.readString(300);
  Serial.println("Settings:");
  Serial.print(ssid);
  Serial.print("|");
  Serial.println(password);
  Serial.println("-----------------------");
  Serial.print(url);
  Serial.print("|");
  Serial.println(port);
  Serial.println("-----------------------");
  Serial.println("Type cli to change these settings");
  cli_init();
  
  sgp.begin();
  tcs.begin();

  //wifi
  setup_wifi();
  //mqtt
  client.setServer(url.c_str(), port.toInt());
  client.setCallback(callback);
}

void loop() {
  if(!cliMode){
    if (!client.connected()) {
      if(trys < 2){
        reconnect();
      }
      else{
        Serial.println("failed:");
        Serial.println("There is a problem with mqtt, change the settings");
        cliMode = true;
        cmd_mqtt();
      }
    }else{    
      RGB_Sensor();
      Gas_Sensor();
      Temp_Sensor();
      delay(1000);
    } 
  }
    my_cli();
}

bool encode(intelliflow_Sensor &sensor){
  uint8_t buffer[50];
  pb_ostream_t stream = pb_ostream_from_buffer(buffer, sizeof(buffer));
  if(!pb_encode(&stream, intelliflow_Sensor_fields , &sensor)){
      Serial.println("Failed to encode");
  }else{
    for(int i = 0; i<stream.bytes_written; i++){
      Serial.printf("%02X",buffer[i]);
    }
    Serial.println("");
    if (!client.publish("sensor", buffer, stream.bytes_written)) {
        Serial.println(F("Publishing Failed"));
    } else {
        succes++;
        Serial.println(F("Publish succesful"));
    }
  }
}

void setup_wifi() {

  delay(10);
  // We start by connecting to a WiFi network
  Serial.println();
  Serial.print("Connecting to ");
  Serial.println(ssid);

  WiFi.begin(ssid.c_str(), password.c_str());

  while (WiFi.status() != WL_CONNECTED && !cliMode) {
    delay(500);
    Serial.print(".");
    wifiTrys++;
    if(wifiTrys >= 10){
      cliMode = true;
      Serial.println("");
      Serial.println("Could not connect, change wifi settings");
      cmd_wifi();
    }
  }

  randomSeed(micros());
  if(WiFi.status() == WL_CONNECTED){
    Serial.println("");
    Serial.println("WiFi connected");
    Serial.println("IP address: ");
    Serial.println(WiFi.localIP());
  }
}

void callback(char* topic, byte* payload, unsigned int length) {
  Serial.print("Message arrived [");
  Serial.print(topic);
  Serial.print("] ");
  for (int i = 0; i < length; i++) {
    Serial.print((char)payload[i]);
  }
  Serial.println();

  // Switch on the LED if an 1 was received as first character
  if ((char)payload[0] == '1') {
    digitalWrite(BUILTIN_LED, LOW);   // Turn the LED on (Note that LOW is the voltage level
    // but actually the LED is on; this is because
    // it is active low on the ESP-01)
  } else {
    digitalWrite(BUILTIN_LED, HIGH);  // Turn the LED off by making the voltage HIGH
  }

}

void reconnect() {
  // Loop until we're reconnected
  
  while (!client.connected() && trys <= 1) {
    Serial.print("Attempting MQTT connection...");
    // Create a random client ID
    String clientId = "ESP8266Client-";
    clientId += String(random(0xffff), HEX);
    // Attempt to connect
    if (client.connect(clientId.c_str())) {
      Serial.println("connected");
    } else {      
        Serial.print("failed, rc=");
        Serial.print(client.state());
        Serial.println(" try again in 5 seconds");
        delay(5000);
        trys++;
    }
  }
}

void RGB_Sensor(){ 
  uint16_t r, g, b, c, colorTemp, lux;
  tcs.getRawData(&r, &g, &b, &c);
  colorTemp = tcs.calculateColorTemperature(r, g, b);
  lux = tcs.calculateLux(r, g, b);
  
  intelliflow_Sensor sensor = intelliflow_Sensor_init_zero;
  strcpy(sensor.id, "1");
  sensor.value=colorTemp;
  strcpy(sensor.unit, "K");   
  Serial.println(sensor.value);
  Serial.println(sensor.id);
  Serial.println(sensor.unit);
  encode(sensor);
  Serial.println("-------------------------");
}

void Gas_Sensor(){
  if (! sgp.IAQmeasure()) {
    Serial.println("Measurement failed");
    return;
  }
  
  intelliflow_Sensor sensor = intelliflow_Sensor_init_zero;
  strcpy(sensor.id, "1");
  sensor.value=sgp.eCO2;
  strcpy(sensor.unit, "ppm");   
  Serial.println(sensor.value);
  Serial.println(sensor.id);
  Serial.println(sensor.unit);
  encode(sensor);
  Serial.println("-------------------------");
}

void Temp_Sensor(){
  int reading = analogRead(25);
  float Temp   = (reading - 509)/6.45;
  
  intelliflow_Sensor sensor = intelliflow_Sensor_init_zero;
  strcpy(sensor.id, "1");
  sensor.value=round(Temp);
  strcpy(sensor.unit, "°C");   
  Serial.println(sensor.value);
  Serial.println(sensor.id);
  Serial.println(sensor.unit);
  encode(sensor);
  Serial.println("-------------------------");
}

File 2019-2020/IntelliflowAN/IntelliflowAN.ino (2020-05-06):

#include "entry.pb.h"
#include <dht11.h>
#include "pb_common.h"
#include "pb.h"
#include "pb_encode.h"

#include <WiFi.h>
#include <PubSubClient.h>
#include "config.h"

#define DHT11PIN 4

//wifi connection
WiFiClient espClient;

//mqtt
PubSubClient client(espClient);
long lastMsg = 0;
char msg[50];
uint32_t  messages = 0;
uint32_t succes = 0;

//protobuf
uint8_t buffer[10];
int values = 0;

//temp sensor
dht11 DHT11;
Loggings_Log message = Loggings_Log_init_zero ;
pb_ostream_t stream = pb_ostream_from_buffer(buffer, sizeof(buffer));

//tests
bool wifisetup = false;
int testmode = 1;
uint32_t beforeTest = 0;
uint32_t afterTest  = 0;
uint32_t testDuration = 0;
void setup() {
  //serial
  Serial.begin(115200);
  //mqtt
  client.setServer(mqtt_server, 24075);
  client.setCallback(callback);
  
}

void loop() {
  switch(testmode){
    case 1: //test the wifi speed
      beforeTest = millis();
      setup_wifi();
      afterTest = millis();
      testDuration = afterTest - beforeTest;
      Serial.print("the wifi test took ");
      Serial.print(testDuration);
      Serial.println(" milliseconds");
      testmode = 2;
      break;
    case 2: //test the mqtt speed
      if(!wifisetup)
        setup_wifi();
      message.temperature = 55;
      if(!encode())
        Serial.println("encoding failed");
      if (!client.connected()) {
        reconnect();
      }
      beforeTest = millis();
      pub();
      afterTest = millis();
      testDuration = afterTest - beforeTest;
      Serial.print("the mqtt test took ");
      Serial.print(testDuration);
      Serial.println(" milliseconds");
      testmode = 3;
      break;
    case 3: //test the protobuf speed
      beforeTest = millis();
      message.temperature = 66;
      for(int i=0; i < 100; i++){
        encode();
        resetValues();
      }
      afterTest = millis();
      testDuration = afterTest - beforeTest;
      Serial.print("the protobuff test took ");
      Serial.print(testDuration);
      Serial.println(" milliseconds");
      testmode = 4;
      break;
  }
}

bool encode(){
  if(!pb_encode(&stream, Loggings_Log_fields, &message)){
      Serial.println("Failed to encode");
      return false;
  }
  return true;
}
bool pub(){
  messages++;
  if (!client.publish("temperature", buffer, stream.bytes_written)) {
    Serial.println(F("Publishing Failed"));
    resetValues();
  } else {
    succes++;
    Serial.println(F("Publish succesful"));
    resetValues();
  }
  Serial.print("succes-rate: ");
  Serial.print(succes);
  Serial.print("/");
  Serial.println(messages);
}

void setup_wifi() {
  wifisetup = true;
  delay(10);
  // We start by connecting to a WiFi network
  Serial.println();
  Serial.print("Connecting to ");
  Serial.println(ssid);

  WiFi.begin(ssid, password);

  while (WiFi.status() != WL_CONNECTED) {
    delay(500);
    Serial.print(".");
  }

  randomSeed(micros());

  Serial.println("");
  Serial.println("WiFi connected");
  Serial.println("IP address: ");
  Serial.println(WiFi.localIP());
}

void callback(char* topic, byte* payload, unsigned int length) {
  Serial.print("Message arrived [");
  Serial.print(topic);
  Serial.print("] ");
  for (int i = 0; i < length; i++) {
    Serial.print((char)payload[i]);
  }
  Serial.println();

  // Switch on the LED if an 1 was received as first character
  if ((char)payload[0] == '1') {
    digitalWrite(BUILTIN_LED, LOW);   // Turn the LED on (Note that LOW is the voltage level
    // but actually the LED is on; this is because
    // it is active low on the ESP-01)
  } else {
    digitalWrite(BUILTIN_LED, HIGH);  // Turn the LED off by making the voltage HIGH
  }

}

void reconnect() {
  // Loop until we're reconnected
  while (!client.connected()) {
    Serial.print("Attempting MQTT connection...");
    // Create a random client ID
    String clientId = "ESP8266Client-";
    clientId += String(random(0xffff), HEX);
    // Attempt to connect
    if (client.connect(clientId.c_str())) {
      Serial.println("connected");
    } else {
      Serial.print("failed, rc=");
      Serial.print(client.state());
      Serial.println(" try again in 5 seconds");
      // Wait 5 seconds before retrying
      delay(5000);
    }
  }
}
void resetValues() {
  message.temperature = 0;
  memset(buffer, 0, sizeof(buffer));
  stream = pb_ostream_from_buffer(buffer, sizeof(buffer));
}

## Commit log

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2020-04-01 Veranderingen deel 1
    - Originele IDAC is verwijderd in de tekst en PCB schema
    - PCB werd herdesigned
    - Verbindingen werden opnieuw gelegt met 40 mil
    - ADC zou nog verbonden moeten worden.
    [ADC.PcbLib, ADC.SchDoc, DAC.PcbLib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]
2020-04-02 Veranderingen deel 2
    - Pushen elektrisch schema en PCB schema
    [PCB_Project.PrjPcb, TestPCB1.SchDoc]
2020-04-02 Verandering 3
    - Verandering pinnen elektrische schema
    - PCB design verder verbonden
    - ADC moet nog verbonden worden in het PCB
    [Connectoren.SchLib, TBL007A_500_connectoren.PcbLib, TestPCB1.SchDoc]
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2020-04-05 iDAC toegevoegd aan schema
    [PCB_Project.PrjPcb, TestPCB1.SchDoc]
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2020-04-06 idac en current to voltage converter, Vref en VSS moeten nog gedaan worden
    [TestPCB1.SchDoc]
2020-04-06 Verandering deel 7
    - Volledige connectoren zijn herzien.
    - Idac is geplaatst en de current to voltage schakeling
    - Idac moet nog grotendeels verbonden worden
    - Schema zijn nog wat kleine verbindingen
    [Connectoren.SchLib, TestPCB1.SchDoc]
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2020-04-07 Verandering deel 11
    - Nakijken elektrische schema
    - Bijwerken PCB design
    [Connectoren.SchLib, TestPCB1.SchDoc]
2020-04-08 Verandering deel 12
    - Afwerken lijst github pcb problems
    - Nog te doen : 45 graden en t spitsingen nakijken
    - Nakijken voor minimin silver error uit te schakelen.
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2020-04-10 Verandering deel 13
    - Traces zijn op de juiste dikte
    - Error checking is gebeurd , alleen de vref verbindingen en tis in orde
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2020-04-12 Vss en Vref toegevoegd
    [TestPCB1.SchDoc]
2020-04-12 project vergete op te slaan
    [PCB_Project.PrjPcb]
2020-04-12 Verandering deel 15
    - Opamp apart gezet.
    - Deel labels gedraait.
    [TestPCB1.SchDoc]
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2020-04-13 Verandering deel 16
    - Printplaat nazicht is gebeurd
    - -3.3V toegevoegt
    - Opschonen elektrische schema
    - Alles zou in orde moeten zijn
    [PCB_Project.PrjPcb, TestPCB1.SchDoc]
2020-04-16 Verandering deel 17
    -Verwijdering schoonheidsfouten
    [TestPCB1.SchDoc]
2020-04-17 Verbeteren fouten
    - Design rule check geeft nu 0 fouten.
    - Verbindingen nagecheckt
    [TestPCB1.SchDoc]
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2020-04-24 added example connection to dashboard
    [partitions_example.csv]
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2020-04-27 Plaatsing UART + algemene layout
    - UART geplaats
    - Lay out aangepast
    [Connectoren.SchLib, TestPCB1.SchDoc]
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2020-05-12 Update mappen PCB
    - Overbodige bestanden zijn weggegooeit
    [ADC1247.SchLib, Components - 18.03.20 - 09.23.SchLib, I2CConnector.PcbLib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]
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2020-09-28 DAC
    - Vorige IDAC werd verwijderd
    - Schematic DAC werd aangemaakt
    - DAC is nu toegevoegt aan het elektrische schema
    Nota = SPI verbinding nakijken en wrs extra connector voor impedance naar current to voltage voor uitlezing ESP32
    [DAC7051.SchLib, TestPCB1.SchDoc]
2020-09-28 footprint DAC
    - 2d en 3d footprint is nu aanwezig
    [Connectoren.SchLib, DAC70504RTET.PcbLib, PCB_Project.PrjPcb]
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2020-09-28 PCB DAC
    - Dac werd toevoegt
    - Traces zijn verbonden
    - Current to voltage zou nog erop moeten
    nota : Voor SPI is het aangeraden dat de traces even lang zijn. Wrs ook voor I2C en UART
    [DAC7051.SchLib, PCB_Project.PrjPcb, TestPCB1.SchDoc]
2020-09-30 Communicatie verbetering
    - SPI = traces zijn even lang
    - I2C = traces zijn even lang
    - UART = traces zijn even lang
    [TestPCB1.SchDoc]
2020-10-01 Communicatie
    - Communicatie herbekeken en verbeterd
    - Extra poort toegevoegt voor impedancy sensoren
    - Nog te doen : current to voltage circuit impedancy sensoren
    [Connectoren.SchLib, TestPCB1.SchDoc]
2020-10-02 changed the github directories and added a api
    [1729034.stp, 1729186.stp, 754-RG2012N-470-W-T1.PcbLib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]
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2020-10-02 Fout opgelost
    - fout connectoren + lijn lengte is opgelost
    [TestPCB1.SchDoc]
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2020-10-08 Glitch footprint ESP32 is weg
    - Oppervalkte footprint was 3 maal groter dan de footprint zelf.
    - Niet gevonden hoe ik dit kon oplossen. Dan maar opnieuw gemaakt
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2020-10-24 Update testplan
    - GPIO's pins
    - More structure
    - Speedcheck
    [Test_Plan_PCB.xlsx]
2020-10-25 Update Test plan
    - Input only pins documented
    - I2C and SPI added in speedcheck
    [Test_Plan_PCB.xlsx]
2020-10-27 Adding stuff in test plan
    - ADC
    - DAC
    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
    [Test_Plan_PCB.xlsx]
2020-10-28 string problem fixed with .options file
    [Intelliflow.ino]
2020-10-30 Testing GPIO
    - GPIO code written
    - GPIO code tested
    - 2 connection errors found
    [Test_Plan_PCB.xlsx]
2020-10-30 Adding comments
    - Research pins RESET and DRYD
    - Adding printscreens with informations pins
    [Test_Plan_PCB.xlsx]
2020-11-03 celsius pub
    other units not working
    [Intelliflow.ino]
2020-11-03 new pcb project + added libraries + correct nodemcu
    [Intelliflow_V_2.PrjPcb, Schema_V_2.SchDoc]
2020-11-03 corrected fault on nodeMcu lib
    [Schema_V_2.SchDoc]
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2020-11-04 added current to voltage converter + all connectors to scheme
    [Schema_V_2.SchDoc]
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2020-11-07 UART
    - UART master testcode added
    - UART slave testcode added
    - first test with UART
    [Test_Plan_PCB.xlsx, UART_Test_Slave.sdf]
2020-11-08 Uart test complete
    - Adding psoc project slave code
    - Update test plan with comments
    - gitignore update
    [Test_Plan_PCB.xlsx, UART_Slave.sdf, UART_Test_Slave.sdf]
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2020-11-10 I2C test completed
    - Technical issue I2C psoc
    - Tested MCP9808 temp sensor on 100 khz and 400 khz : Both passed
    - Edditing testplan
    - Next SPI , basic slave code PSOC added , basic SPI_Master added
    [I2C_slave.sdf, SPI_Slave.sdf, Test_Plan_PCB.xlsx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]
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2020-11-12 replaced connector
2020-11-13 Adding SPI test codes
    - Psoc recieved string from ESP
    [SPI_Slave.sdf]
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2020-11-20 adding SPI codes
    - Adding / edditing master and slave codes for testing purpose
    [I2C_slave.sdf, SPI_Slave.sdf, SPI_Slave_FullDuplex.sdf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]
2020-11-22 SPI testing complete
    - Codes adjusted
    - Adding results to testplan
    [SPI_Slave_FullDuplex.sdf, SPI_Slave_HalfDuplex.sdf, Test_Plan_PCB.xlsx]
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2020-11-26 sensor beta
    not working
2020-11-27 Testing completed PCB v1
    - Commenting/finalizing testplan PCB
    - Update psoc codes
    [SPI_Slave_FullDuplex.sdf, SPI_Slave_HalfDuplex.sdf, Test_Plan_PCB.xlsx]
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2020-12-04 changed error when not connected to wifi
    [Intelliflow.ino]
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2021-01-03 Little maintance testcode
    - Chaning function name
    - Providing better output for presentation
    [SPI_Slave_FullDuplex.sdf, UART_Slave.sdf]
